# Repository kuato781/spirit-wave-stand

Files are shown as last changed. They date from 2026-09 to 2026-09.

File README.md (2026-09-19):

# Folding Indexed Stand for the Spirit WAVE

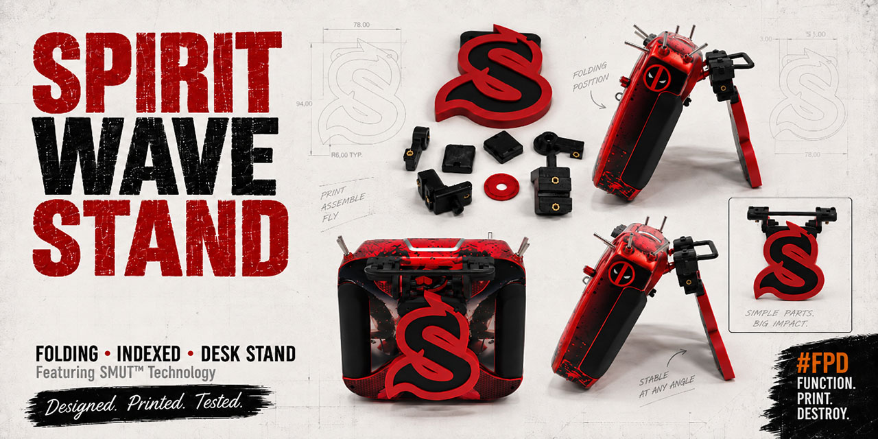
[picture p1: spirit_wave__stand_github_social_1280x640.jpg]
Spirit WAVE Stand


A folding, indexed-position desk stand designed for the round carrying handle on the Spirit WAVE transmitter.

The stand mounts without permanently modifying the radio, folds against the back, preserves normal access to the carrying handle, and uses a spring-loaded ball plunger with a replaceable detent ring to provide positive indexed positions.

This project is a Spirit WAVE implementation of **SMUT™** — **S**ide **M**ount **U**nit **T**echnology — the same retained-pivot architecture proven on the Spektrum iX14, adapted here with WAVE-specific handle cases and a WAVE-specific stand/header.

## What Changed for the WAVE?

The pivot and detent mechanism is intentionally familiar:

- independent left and right retained pivots;
- replaceable keyed detent ring;
- M4 × 0.7 spring-loaded ball plunger;
- square keyed stand blocks that carry shear and twisting load;
- M3/M4 heat-set inserts and conventional metric hardware.

The radio-specific pieces are the **WAVE handle cases/caps** and the **stand/header geometry**.

The WAVE handle cases follow the actual round metal handle path, while the stand uses a reusable 46 mm-center **Header Mule** mechanical core. That makes the architecture:

**standardized mechanical header + radio-specific case interface + whatever stand body you want**

The supplied Spirit-S stand is one implementation of that architecture.

## Start Here

- [Assembly instructions](documentation/assembly-instructions/assembly-instructions.md)
- [Printable three-stage assembly guide](documentation/exploded-view/SpiritWave-assembly-guide.pdf)
- [Hardware buy list](buy-list/Spirit%20WAVE%20Stand%20-%20Buy%20List.md)
- [Bambu Studio notes](bambu-studio-3mf/bambu-studio-profile.md)
- [Individual STL/SCAD files](stl-scad/)
- [Product photos](documentation/product-images/)

For Bambu Studio users, ready-to-slice projects are provided separately for the mounting hardware and stand:

- [SpiritWave_all_mounting_hardware.3mf](bambu-studio-3mf/mounting-hardware/SpiritWave_all_mounting_hardware.3mf)
- [SpiritWave-Stand.3mf](bambu-studio-3mf/stand/SpiritWave-Stand.3mf)

A merged stand STL is also provided for non-Bambu workflows:

- [SpiritWave-Stand-merged.stl](stl-scad/stand/SpiritWave-Stand-merged.stl)

## Product Photos

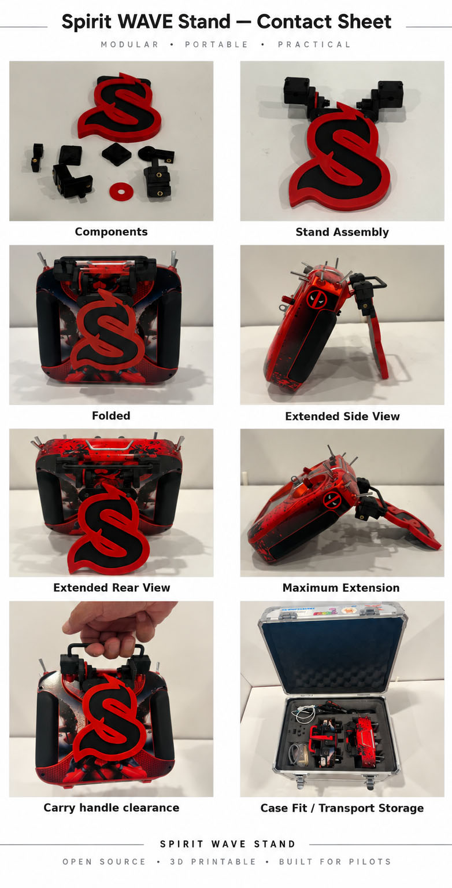
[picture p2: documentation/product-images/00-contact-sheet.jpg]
Spirit WAVE stand contact sheet


The product-image directory contains photographs of the actual printed parts and completed assembly, including separate components, assembled and folded positions, extension views, carrying-handle clearance, and transport-case fit.

These are photographs of the physical build, not CAD renders.

## Important WAVE-Specific Assembly Notes

### Ball-plunger insert collar

Because of the print geometry around the M4 ball-plunger insert, the collar may not seat perfectly cleanly after printing.

If needed, **lightly clean the collar/opening with a reamer** before installing the insert. Remove only enough material to clean up the printed opening; do not enlarge the bore unnecessarily.

### Common case caps

The two case caps are identical. There is no left cap and right cap.

Install each cap with the **beveled edge facing away from the radio**.

Tighten the cap screws until you feel a **good bite** and the cases are secure on the handle. A **visible gap between the cap and case body is normal**; the cap does not need to close flush.

Do not keep tightening simply to eliminate the gap.

### Transport case

> **The radio will not fit in the stock Spirit case with this stand installed unless you are willing to modify the case.**

The physical build shown here is transported in a **Spektrum two-radio case**, which is convenient when carrying multiple transmitters.

## Header Mule — Reusable Mechanical Core

The repository includes the SpiritWave Header Mule STL and SCAD in stl-scad/mounting-hardware/.

This header is the reusable mechanical core for alternate stand designs.

A custom stand can be modeled around or through the Header Mule while preserving:

- the 46 mm mounting-center spacing;
- keyed pivot interfaces;
- screw locations;
- header thickness;
- pivot/rotation clearance.

Stand-specific outlines, chamfers, logos, colors and styling can then be added around that mechanical interface.

## Print and Validation Status

The design was developed through repeated physical fitting and printing rather than CAD-only validation:

**measure → model → print → test → revise**

The WAVE-specific case geometry, common cap, pivot mechanism, Header Mule and Spirit-S stand have all been physically printed and fitted.

PETG is the intended production material for the current build. The supplied Bambu Studio projects are the easiest starting point because they preserve the prepared object layout and stand color separation.

As with any 3D-printed mechanical part, verify fit and motion on your own printer before relying on the stand.

## AI-Assisted Design and Development

This project was developed with AI assistance.

AI was used throughout the iterative process to help translate physical measurements into printable geometry, revise handle-path and case fit, preserve and adapt the SMUT™ pivot architecture, develop the reusable Header Mule, refine the stand outline and multicolor geometry, evaluate clearances and fastener placement, and organize printable artifacts and documentation.

The generated geometry was never treated as correct simply because it looked correct on screen.

The printer and the actual radio got the final vote. :-)

## Repository Organization

| Directory | Contents |
|---|---|
| bambu-studio-3mf/ | Ready-to-slice Bambu Studio projects and print notes |
| buy-list/ | Required metric hardware and inserts |
| documentation/assembly-instructions/ | Detailed Markdown assembly instructions |
| documentation/exploded-view/ | Printable PDF assembly guide and page images |
| documentation/product-images/ | Photographs of the physical build |
| stl-scad/mounting-hardware/ | WAVE case hardware, reusable Header Mule and source/reference geometry |
| stl-scad/stand/ | Spirit WAVE stand STL/SCAD components and merged STL |

Unlike the iX14 project, this repository has **no V1/V2 split**. It contains the current Spirit WAVE implementation directly at the repository root.

## Important Safety Information

- This is a desk/simulator stand, **not a replacement carrying handle**.
- Inspect every print, heat-set insert and fastener before use and periodically afterward.
- Confirm the stand is stable before placing the radio on an elevated, uneven or windy surface.
- Never force the stand beyond its intended range of motion.
- Read [DISCLAIMER.md](DISCLAIMER.md) before printing or using the design.

## Unofficial Community Project

This is an independent community project and is not affiliated with or endorsed by Spirit System.

Spirit, Spirit System, WAVE, associated logos and other brand identifiers remain the property of their respective owners. Their appearance here identifies the compatible transmitter and the physical community build; it does not imply sponsorship or endorsement.

## License

This project is provided under the [Creative Commons Attribution-NonCommercial 4.0 International License](LICENSE).

You may print, copy, share and modify the files for noncommercial purposes with attribution. Changes must be identified.

The original files and derivatives may not be sold or otherwise used commercially without separate permission from the creator.

## Why?

Because apparently the natural progression of:

**RC helicopters + 3D printing + AI + excessive iteration**

is building a modular indexed stand architecture and then adapting it to every transmitter that wanders into the shop.

And that's pretty kewl. :-D

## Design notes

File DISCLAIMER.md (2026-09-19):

# Use at Your Own Risk

The design files, models, print profiles, instructions, photographs and other materials in this repository are provided for personal, noncommercial use on an **as-is** and **as-available** basis.

## No warranty

No warranty or representation is made that the materials are accurate, complete, error-free, safe, suitable for a particular purpose or compatible with any specific printer, material, tool, device or application.

3D-printed parts can vary significantly because of printer calibration, filament condition, material selection, slicer settings, print orientation, layer adhesion, environmental exposure, assembly technique, hardware tolerances and normal wear.

## Your responsibility

You are solely responsible for determining whether a design is suitable for your intended use. Before relying on any printed part or procedure, you should:

- Review the design, dimensions, hardware and instructions.
- Confirm that your printer, material and slicer settings are appropriate.
- Inspect every print for cracks, poor layer adhesion, deformation or other defects.
- Verify the fit, alignment, fasteners, inserts and range of motion during assembly.
- Test the completed item in a controlled and safe environment.
- Reinspect printed parts and hardware periodically and replace anything damaged, loose or worn.
- Independently verify any measurements, alignments, control settings or mechanical adjustments that could affect equipment operation or safety.

Do not assume that a successful print or another user's successful result guarantees that your copy will perform the same way.

## Assumption of risk

By downloading, printing, modifying, assembling or using these materials, you accept all associated risks. These may include failed prints, damaged filament or tools, ruined project materials, damage to equipment or property, loss of use and personal injury.

These materials are not professionally engineered, certified or tested as safety equipment. Do not use them for life-support, fall-protection, structural, load-bearing, emergency or other safety-critical applications.

## Radio and carrying case

This stand changes the external profile of the Spirit WAVE transmitter.

The assembled radio does **not** fit the stock Spirit carrying case without modification. Any carrying-case modification, alternate case selection, packing method or transport decision is entirely the user's responsibility.

The stand is a desk/simulator accessory and is **not a replacement carrying handle**.

## Limitation of liability

To the maximum extent permitted by applicable law, the creator and contributors will not be liable for any direct, indirect, incidental, special, consequential, exemplary or other loss, damage, cost or injury arising from the materials or their use, modification, assembly or inability to be used.

## Modifications and redistribution

If you modify or redistribute these materials, clearly identify your changes. You are responsible for validating your modified version and should preserve this disclaimer or provide an equivalent notice to downstream users.

## Trademarks and affiliation

This is an independent community project and is not affiliated with or endorsed by Spirit System.

Spirit, Spirit System, WAVE, associated logos and other brand identifiers remain the property of their respective owners.

## Relationship to the license

This disclaimer supplements the repository's [LICENSE](LICENSE) file and does not replace or modify its terms. If there is any conflict, the license controls.

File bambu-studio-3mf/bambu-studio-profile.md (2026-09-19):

# Bambu Studio Notes — Spirit WAVE Stand

The repository contains two prepared Bambu Studio projects:

- [mounting-hardware/SpiritWave_all_mounting_hardware.3mf](mounting-hardware/SpiritWave_all_mounting_hardware.3mf)
- [stand/SpiritWave-Stand.3mf](stand/SpiritWave-Stand.3mf)

The mounting hardware and stand are separated so they can be printed, reprinted and color-managed independently.

## Recommended material

The current physical build is printed in **PETG**.

Use a PETG profile appropriate for your printer and filament, and verify the printer, build plate, nozzle and filament mapping before slicing.

The supplied 3MF files are the preferred starting point because they preserve the prepared object arrangement and, for the stand, the separate black/red geometry used for multicolor printing.

## Stand color objects

The stand is organized around two visual groups:

1. **BLACK — structural core + header**
2. **RED — Spirit-S accent + outside edge**

The repository also includes individual STL/SCAD components and a merged STL for users who do not want to use the Bambu Studio project.

## Stand ironing

The physically validated cosmetic setup used **Topmost surface** ironing on the visible stand surfaces:

- Pattern: Rectilinear
- Speed: 25 mm/s
- Flow: 12%
- Line spacing: 0.18 mm
- Inset: 0.21 mm

These settings are intended for the cosmetic top surfaces. Vertical sidewalls are controlled by the model geometry and normal perimeter printing, not by ironing.

## Pre-print checks

Before starting a print:

- confirm all active objects are assigned to the intended PETG spools;
- verify the mounting-hardware and stand projects use the correct printer and plate;
- inspect the sliced preview for unexpected supports, gaps or missing color regions;
- confirm the stand's black/red objects remain aligned;
- inspect first layers before leaving the printer unattended.

## Assembly-sensitive printed features

Two printed areas deserve extra attention after printing:

- **M4 ball-plunger insert collar:** because of the print geometry, the collar/opening may need a very light cleanup with a reamer before the insert seats cleanly.
- **Common case caps:** both caps are identical. Install the beveled edge away from the radio. A visible cap-to-body gap is normal after tightening to a good bite.

Do not remove excess material simply to make cosmetic gaps disappear; fit and secure clamping matter more than a flush seam.

## Transport note

The Spirit WAVE with this stand installed does **not** fit the stock Spirit case unless the case is modified.

The documented physical build is transported in a Spektrum two-radio case.

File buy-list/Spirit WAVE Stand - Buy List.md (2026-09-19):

# Spirit WAVE Stand - Buy List

The Spirit WAVE implementation reuses the proven SMUT™ pivot/detent hardware from the Spektrum iX14 V2 design. The case geometry and stand are radio-specific, but the insert and fastener stack is otherwise the same.

### Heated inserts
- [ ] **6 × M3 heat-set inserts**, approximately **5 mm OD × 5 mm long**
- [ ] **1 × M4 heat-set insert**, approximately **6 mm OD × 6 mm long**

### Ball plunger
- [ ] **1 × M4 × 0.7 spring-loaded ball plunger**
  - Approximately **8-9 mm overall threaded-body length**
  - Approximately **2.5 mm ball**
  - Tested hardware elastic range: **3-15 N**

### Bolts, washers and nuts
- [ ] **2 × M4 × 20 mm socket-head or button-head screws**
- [ ] **2 × M4 Nyloc nuts**
- [ ] **2 × M4 flat washers**
- [ ] **4 × M3 × 12 mm socket-head or button-head screws**
- [ ] **2 × M3 × 8 mm button-head screws**
- [ ] **2 × M3 flat washers**

### Optional
- [ ] Small amount of **removable, non-permanent threadlocker** (for example, blue Loctite) for the ball-plunger threads

> **Note:** The Spirit WAVE cases use the same insert and fastener arrangement as the proven iX14 V2 SMUT™ mechanism. The WAVE-specific changes are the handle-fitting case geometry and the stand/header geometry.

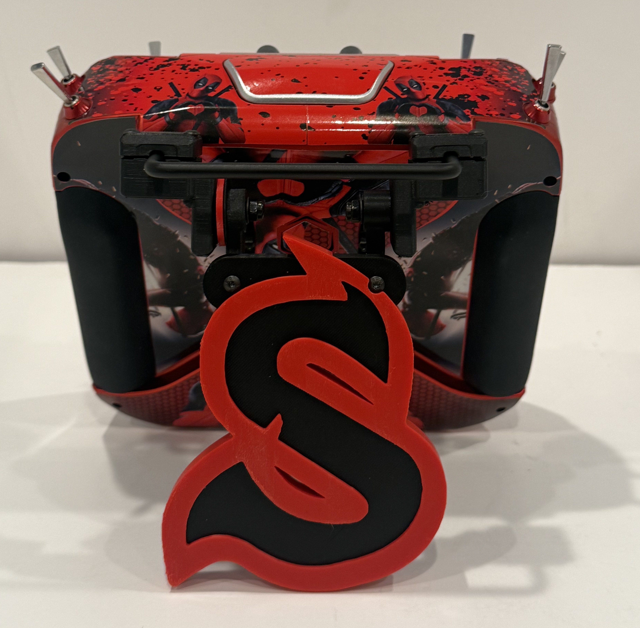
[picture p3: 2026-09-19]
documentation/product-images/05-extended.jpg

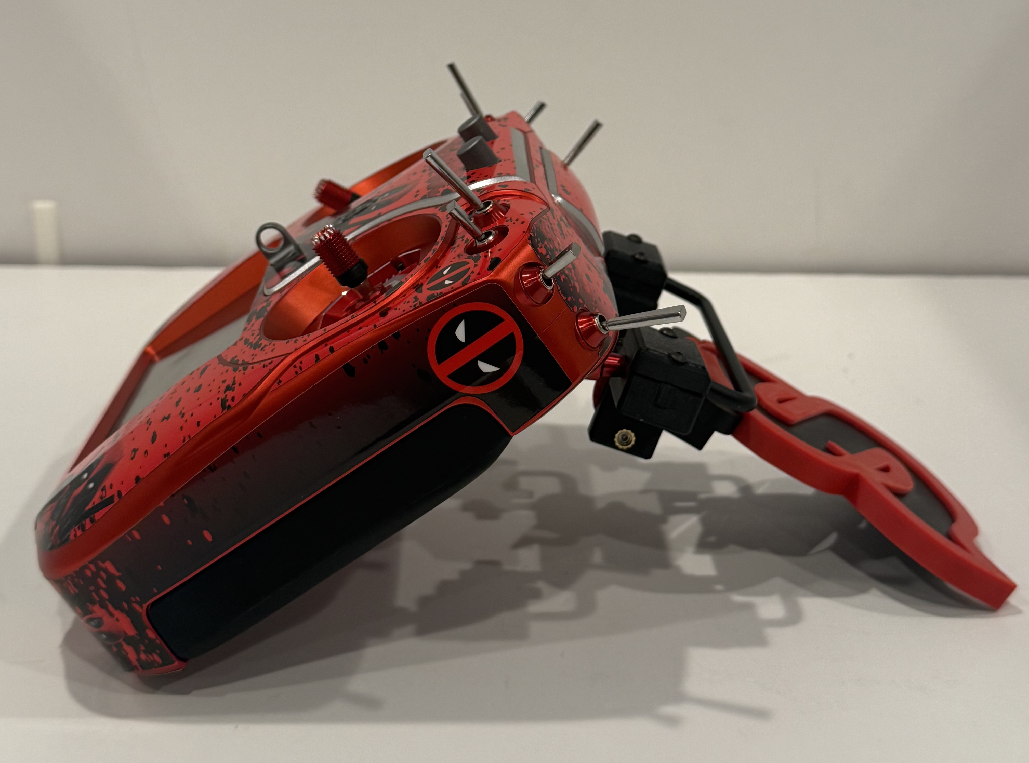
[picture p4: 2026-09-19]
documentation/product-images/07-extended_side_max.jpg

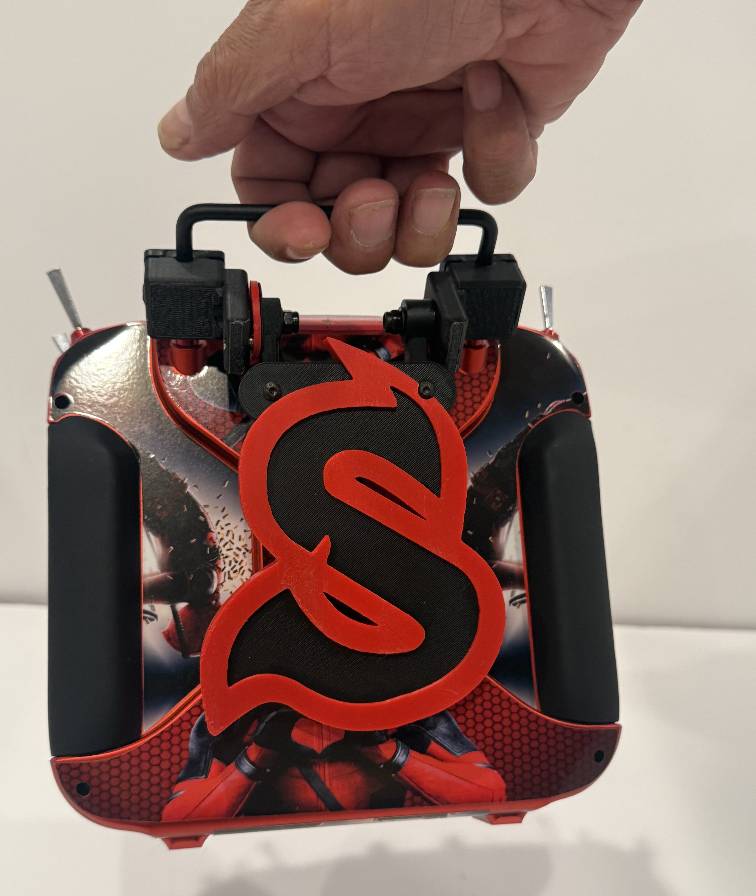
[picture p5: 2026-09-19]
documentation/product-images/08-clearance.jpg

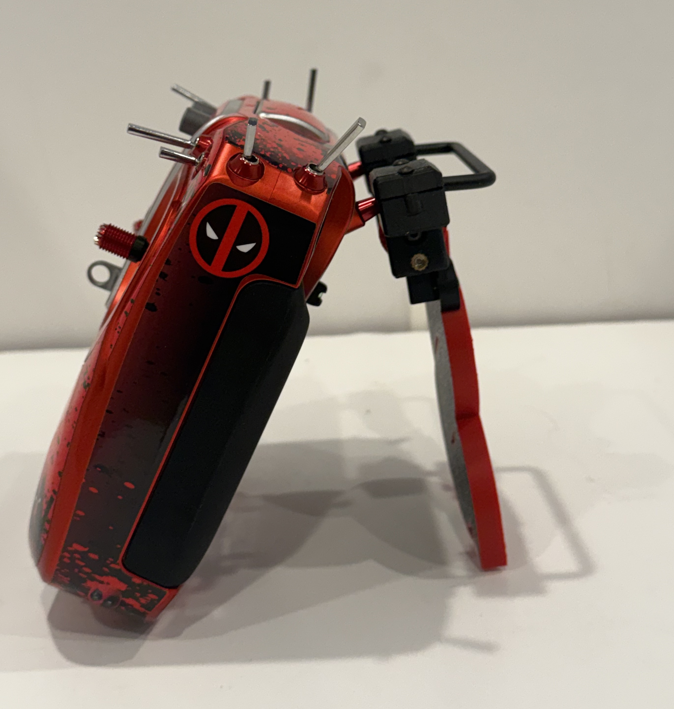
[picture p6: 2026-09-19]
documentation/product-images/04-extended_side.jpg

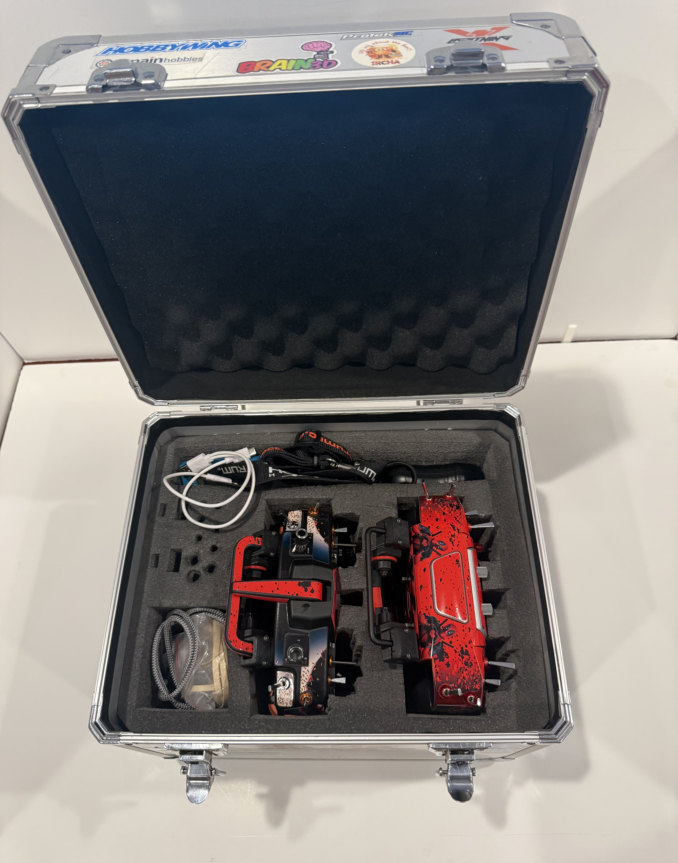
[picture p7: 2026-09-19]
documentation/product-images/10-carrier-fit.jpg

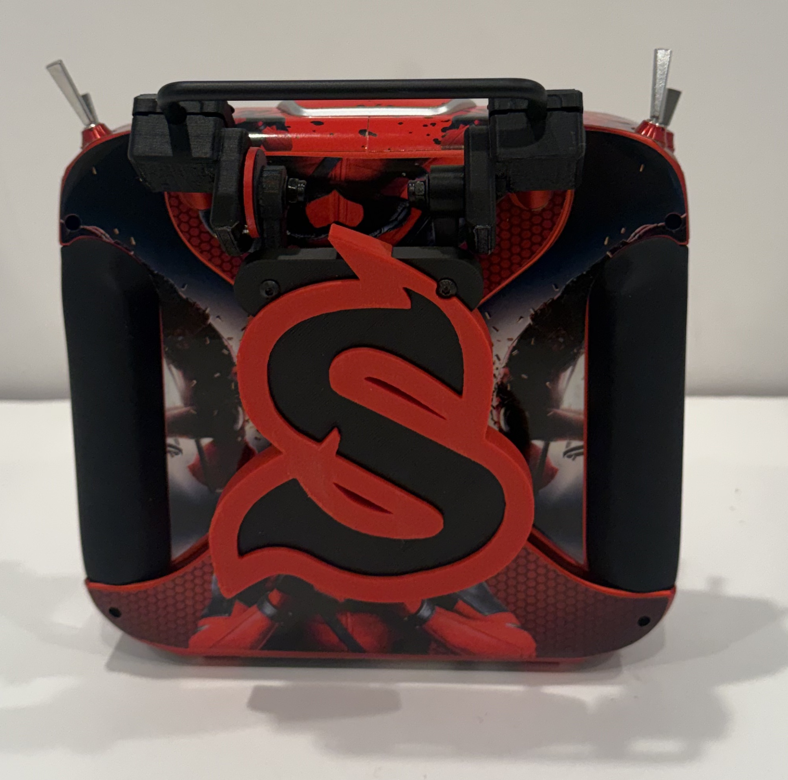
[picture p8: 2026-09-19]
documentation/product-images/03-folded.jpg

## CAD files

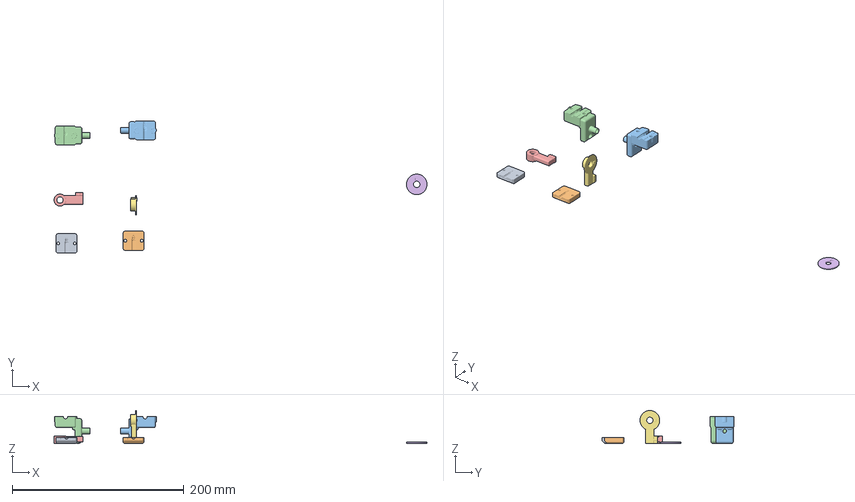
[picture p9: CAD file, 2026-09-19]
bambu-studio-3mf/mounting-hardware/SpiritWave_all_mounting_hardware.3mf
435.0 x 154.2 x 38.5 mm
SpiritWave-common-case-cap.stl x 2
SpiritWave-left-plain-case-body.stl
SpiritWave-right-detent-case-body.stl
SpiritWave-left-plain-pivot-stub.stl
SpiritWave-replaceable-detent-ring.stl
SpiritWave-right-detent-pivot-stub.stl

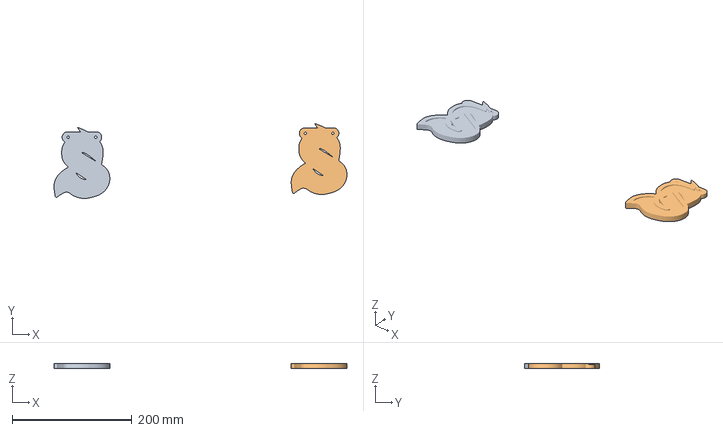
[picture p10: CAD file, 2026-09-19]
bambu-studio-3mf/stand/SpiritWave-Stand.3mf
488.6 x 124.7 x 9.00 mm
Assembly
SpiritWave-Stand-merged.stl

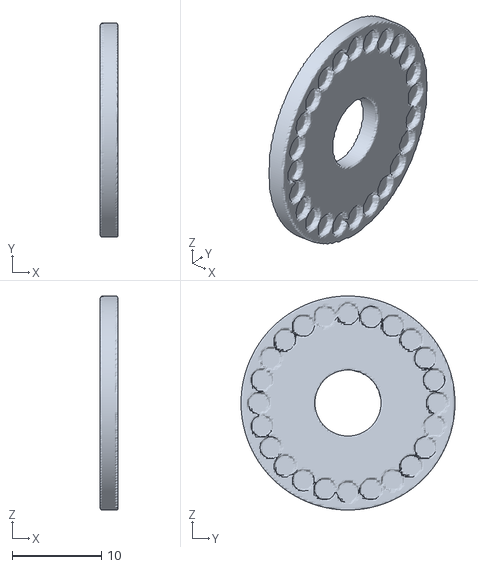
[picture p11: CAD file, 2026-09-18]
stl-scad/mounting-hardware/SpiritWave-replaceable-detent-ring.stl
2.00 x 24.0 x 24.0

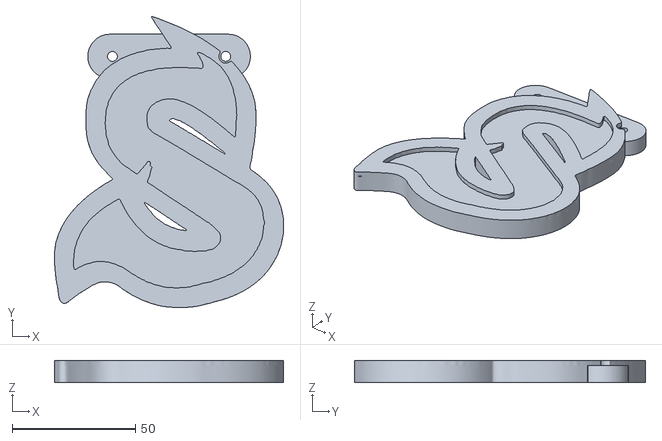
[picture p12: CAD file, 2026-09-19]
stl-scad/stand/SpiritWave-Stand-merged.stl
93.1 x 118.1 x 9.00

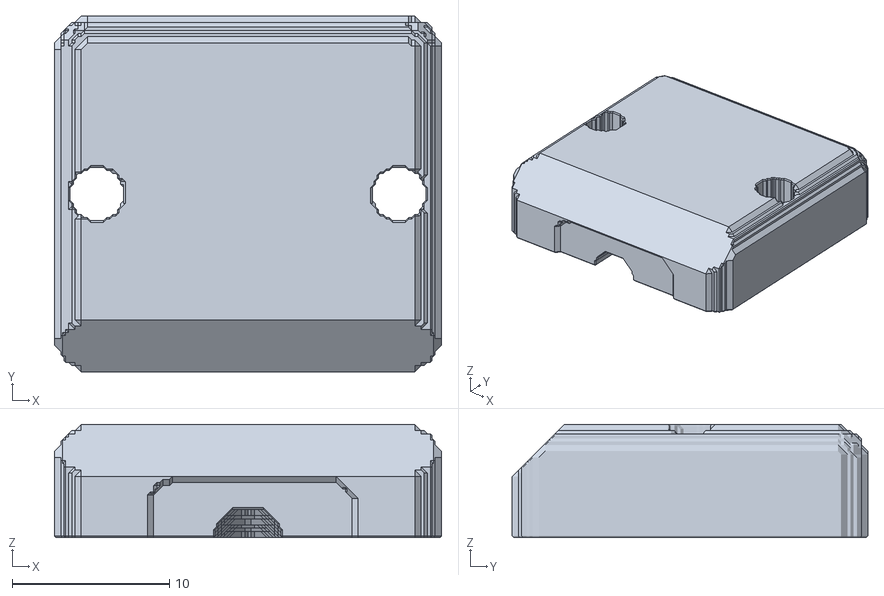
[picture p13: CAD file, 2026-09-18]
stl-scad/mounting-hardware/SpiritWave-common-case-cap.stl
24.6 x 22.6 x 7.20

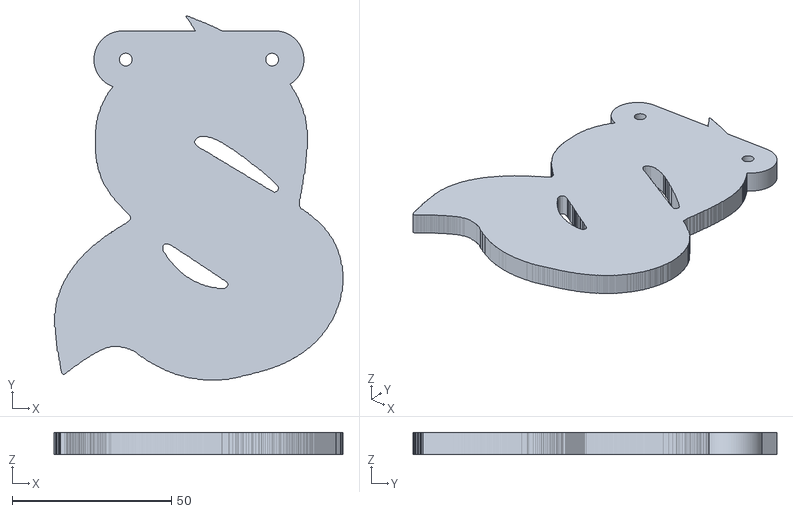
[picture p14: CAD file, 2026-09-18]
stl-scad/stand/SpiritWave-BLACK.stl
90.8 x 114.4 x 7.00

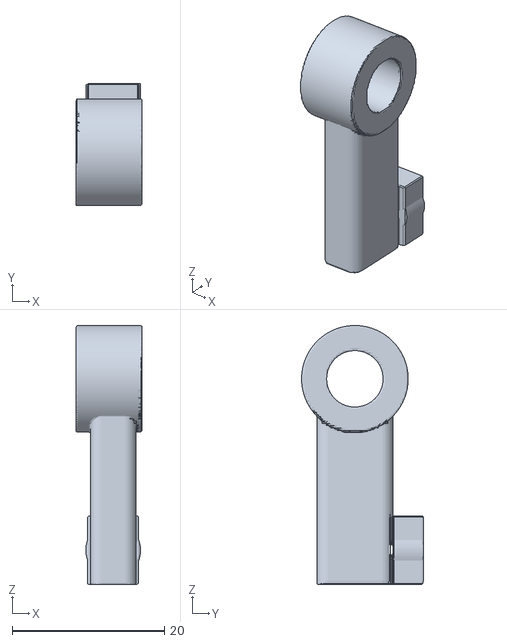
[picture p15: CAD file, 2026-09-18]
stl-scad/mounting-hardware/SpiritWave-left-plain-pivot-stub.stl
8.70 x 16.0 x 34.0

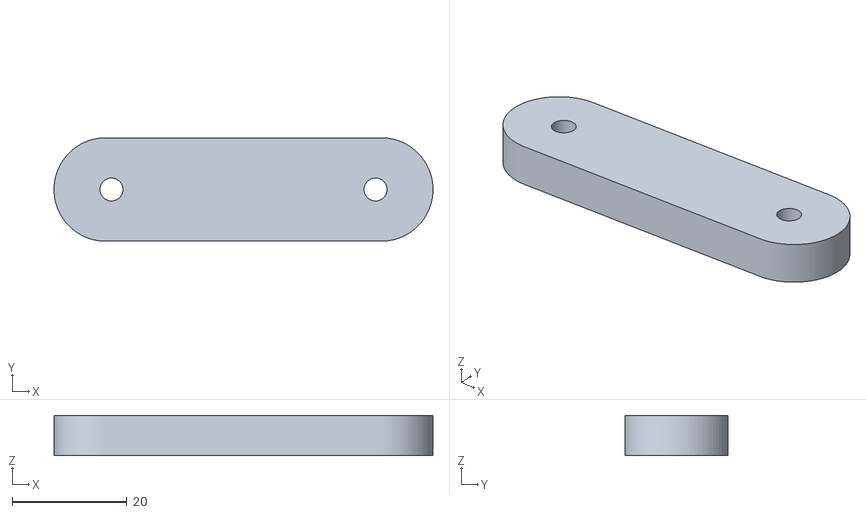
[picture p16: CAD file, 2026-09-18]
stl-scad/stand/SpiritWave-BLACK-HEADER.stl
66.0 x 18.0 x 7.00

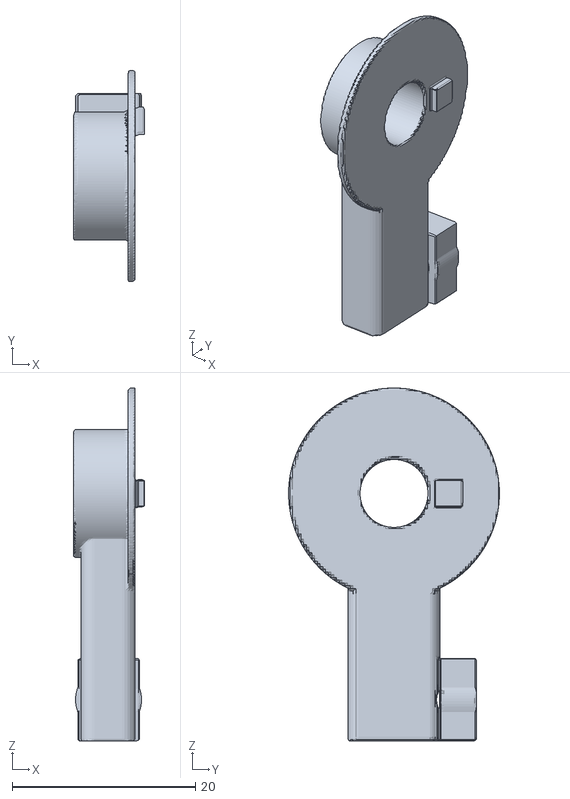
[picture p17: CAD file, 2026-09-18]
stl-scad/mounting-hardware/SpiritWave-right-detent-pivot-stub.stl
7.70 x 23.0 x 38.5

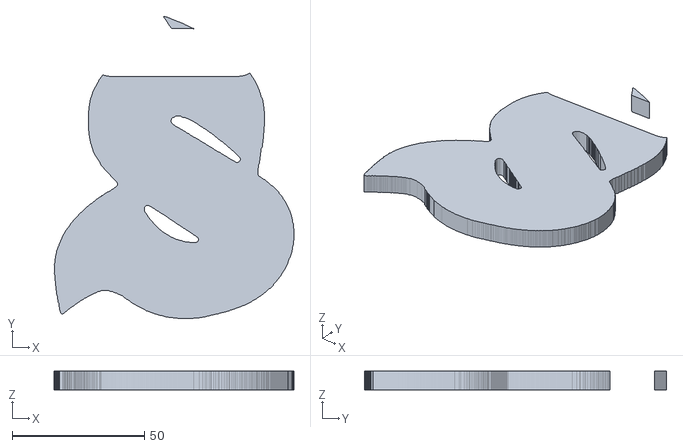
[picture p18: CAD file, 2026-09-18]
stl-scad/stand/SpiritWave-BLACK-BODY.stl
90.8 x 114.4 x 7.00

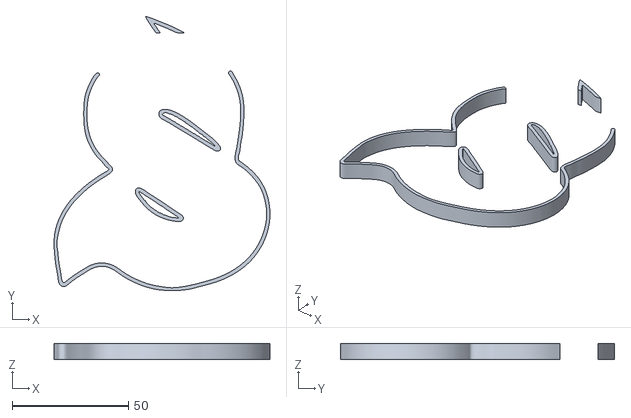
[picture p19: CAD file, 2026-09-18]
stl-scad/stand/SpiritWave-RED-LOWER.stl
93.1 x 118.1 x 7.00

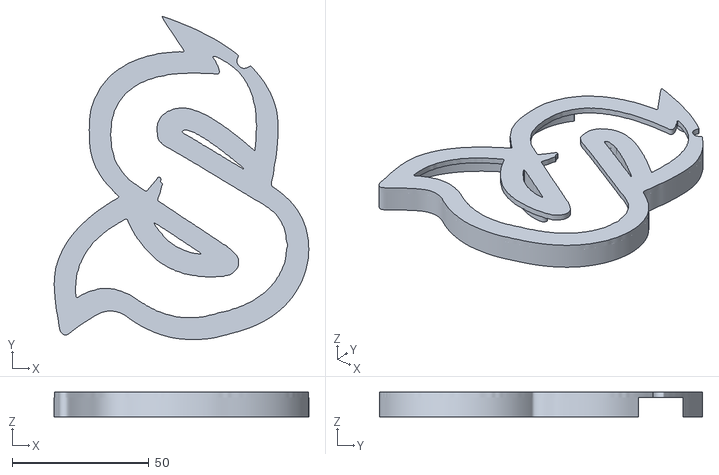
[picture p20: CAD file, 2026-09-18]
stl-scad/stand/SpiritWave--RED.stl
93.1 x 118.1 x 9.00

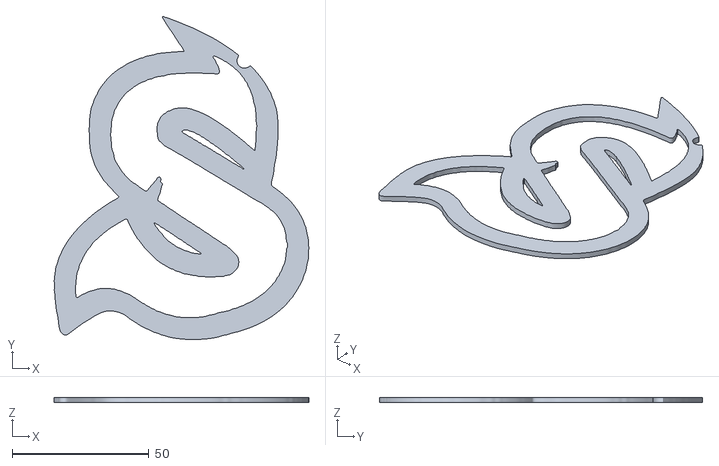
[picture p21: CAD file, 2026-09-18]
stl-scad/stand/SpiritWave--RED-RAISED.stl
93.0 x 118.1 x 2.00

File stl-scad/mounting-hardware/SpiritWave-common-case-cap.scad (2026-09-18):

// Spirit WAVE SMUT™ — Mule 0.16 common case-cap source reference
//
// The 0.16 common cap is carried forward unchanged from the proven 0.11 cap.
// The printable STL in the package is the authoritative frozen geometry.

fit_d = 4.90;              // Spirit WAVE round-handle channel
m3_clearance_d = 3.40;     // free-pass M3 cap screw hole
cap_bottom_trim = 1.00;    // 0.11: shortened 1 mm from bottom

// Round handle architecture:
// cap receives the TOP 180° of the 4.90 mm channel;
// case body receives the BOTTOM 180° cradle.
// Left/right use the same common cap because the WAVE rails are parallel.

// Insert/collar geometry belongs to the case body, not this cap.

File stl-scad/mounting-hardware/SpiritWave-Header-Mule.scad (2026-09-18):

DONOR="/mnt/data/ix14_v2_stand.stl";
SHIFT=1.5; YMIN=-9; YMAX=9; ZMIN=0; ZMAX=7;
R=9; C=24; PIVOT_X=23; THRU_R=2; BOTTOM_FILL_H=1.05;

module donor_header(){
  intersection(){
    import(DONOR,convexity=30);
    translate([-100,YMIN,ZMIN]) cube([200,YMAX-YMIN,ZMAX-ZMIN]);
  }
}
module left_half(){
  intersection(){
    donor_header();
    translate([-100,-100,-10]) cube([100,200,30]);
  }
}
module right_half(){
  intersection(){
    donor_header();
    translate([0,-100,-10]) cube([100,200,30]);
  }
}
module widened_header(){
  union(){
    translate([-SHIFT,0,0]) left_half();
    translate([SHIFT,0,0]) right_half();
    translate([-SHIFT,YMIN,ZMIN]) cube([2*SHIFT,YMAX-YMIN,ZMAX-ZMIN]);
  }
}
module capsule_2d(){
  hull(){
    translate([-C,0]) circle(r=R,$fn=180);
    translate([ C,0]) circle(r=R,$fn=180);
  }
}
module capsule_header(){
  intersection(){
    widened_header();
    linear_extrude(height=ZMAX,convexity=30) capsule_2d();
  }
}
module bottom_flat_fill(){
  difference(){
    linear_extrude(height=BOTTOM_FILL_H,convexity=30) capsule_2d();
    for(x=[-PIVOT_X,PIVOT_X])
      translate([x,0,-0.1]) cylinder(h=BOTTOM_FILL_H+0.2,r=THRU_R,$fn=96);
  }
}
union(){
  capsule_header();
  bottom_flat_fill();
}

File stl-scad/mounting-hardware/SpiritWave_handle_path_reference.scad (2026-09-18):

// Spirit WAVE SMUT™ — proven Mule 0.5 handle-path reference
fit_d = 4.90;
straight = 10.0;
bend_r = 6.0;
bend_deg = 15.047020063425533;
tail_len = 10.102419240115;
seam_z = 2.70;
// Strict centerline: straight -> ONE circular bend -> tangent straight.

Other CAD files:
stl-scad/mounting-hardware/SpiritWave-Header-Mule.stl
stl-scad/stand/SpiritWave--RED.scad
stl-scad/stand/SpiritWave-RED-LOWER.scad
stl-scad/stand/SpiritWave-RED-RAISED.scad

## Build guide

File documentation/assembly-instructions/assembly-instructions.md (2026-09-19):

# Assembly Instructions - Spirit WAVE Stand SMUT™ System

[Download the printable three-stage assembly guide (PDF)](../exploded-view/SpiritWave-assembly-guide.pdf)

These instructions apply to the Spirit WAVE implementation of **SMUT™** - **S**ide **M**ount **U**nit **T**echnology. The mechanism uses independent left and right pivot assemblies clamped around the WAVE's round metal handle, then joins them with the Spirit WAVE stand/header assembly.

**Left and right are always described while looking at the front of the radio.**

> **Hardware status:** the pivot, detent and mounting hardware are carried forward from the physically validated iX14 SMUT™ mechanism. The Spirit WAVE uses radio-specific case geometry and a WAVE-specific stand/header while retaining the same pivot-stub, replaceable detent-ring and ball-plunger architecture.

## Recommended print files

For Bambu Studio users:

- [Spirit WAVE mounting hardware 3MF](../../bambu-studio-3mf/mounting-hardware/SpiritWave_all_mounting_hardware.3mf)
- [Spirit WAVE stand 3MF](../../bambu-studio-3mf/stand/SpiritWave-Stand.3mf)

Individual STL/SCAD files are also available under stl-scad/. A merged stand STL is available at [SpiritWave-Stand-merged.stl](../../stl-scad/stand/SpiritWave-Stand-merged.stl).

## Printed parts

| Quantity | Part |
| ---: | --- |
| 1 | Left plain case body |
| 2 | Common case cap |
| 1 | Left plain pivot stub |
| 1 | Right detent case body |
| 1 | Right detent pivot stub |
| 1 | Replaceable detent ring |
| 1 | Spirit WAVE stand assembly |

The reusable **SpiritWave Header Mule** is provided as a design core/reference for alternate stand bodies. It is already incorporated into the supplied stand and is **not an additional printed part** when using the current stand 3MF.

Use the [Spirit WAVE buy list](<../../buy-list/Spirit WAVE Stand - Buy List.md>) for the complete hardware list.

## Insert locations

Install all heat-set inserts before mounting the cases to the radio.

- **4 × M3 inserts:** two reinforced cap-screw pockets in each case body
- **2 × M3 inserts:** one square stand-mounting block on each pivot stub
- **1 × M4 insert:** spring-plunger bore in the right detent case body

Use the alignment feature supplied with your heat-set tool, such as an insert-centering nub, whenever one is available. If your heat-set setup does not already provide an alignment solution, an appropriate screw may be threaded loosely into the insert to help keep it straight. Press the insert into its reinforced collar and allow the part to cool completely before applying load.

> **Ball-plunger insert collar:** because of the nature of the print and the location of the M4 plunger insert, the printed collar/opening may not seat perfectly cleanly. If needed, **lightly clean it with a reamer** before installing the insert. Remove only enough material to clean the opening; do not unnecessarily enlarge the bore.

[Stage 1: build the left and right pivot assemblies](../exploded-view/images/step1.png)

## 1. Assemble the right detent pivot

1. Place the replaceable detent ring on the support face of the right detent pivot stub.
2. Align the asymmetric square key and recess. The ring should seat fully without force.
3. Orient the detent pockets toward the right case body and its ball-plunger bore.
4. Slide the right pivot stub over the case body's 7 mm pivot sleeve.
5. Install the M4 pivot screw through the case body, sleeve and stub.
6. Fit the M4 washer on the Nyloc side, then install the M4 Nyloc nut.
7. Tighten until the hardware is firmly seated. Confirm that the sleeve shoulder prevents the stub from being pinched and that the stub still rotates freely.

## 2. Assemble the left plain pivot

1. Slide the left plain pivot stub over the left case body's pivot sleeve.
2. Install the M4 pivot screw through the case body, sleeve and stub.
3. Fit the M4 washer on the Nyloc side, then install the M4 Nyloc nut.
4. Tighten until firmly seated and confirm smooth, free rotation.

## 3. Mount the case assemblies to the WAVE handle

[Stage 2: attach the case assemblies to the WAVE handle](../exploded-view/images/step2.png)

1. Place the completed left and right case assemblies around their corresponding sides of the Spirit WAVE round metal handle.
2. Fit one **common case cap** to each case body. The two caps are identical; there is no left/right cap assignment.
3. Orient each common cap with its **beveled edge facing away from the radio**.
4. Make sure the handle is fully seated in the curved channel in each case and cap.
5. Install two M3 × 12 screws through each cap.
6. Snug the four cap screws only enough to hold the assemblies in position while the stand/header is fitted and used to square both sides.

Washers are not required under the case-cap screws.

> **Normal cap fit:** after final tightening there will be a **visible gap** between each cap and case body. This is expected. Tighten until you feel a **good bite** and the assembly is secure on the handle; do not overtighten simply to force the cap flush.

## 4. Attach the Spirit WAVE stand

[Stage 3: attach, square and tighten the Spirit WAVE stand](../exploded-view/images/step3.png)

1. Align the stand/header's two keyed recesses with the square mounting blocks on the pivot stubs.
2. Seat both mounting blocks completely in the header recesses.
3. Install one M3 × 8 button-head screw and M3 washer through each header hole and into the insert in the corresponding pivot-stub block.
4. Leave both stand screws slightly loose during alignment.

The keyed mounting blocks carry the stand's shear and twisting loads; the M3 screws retain and clamp the connection.

## 5. Square and tighten the assembly

1. Push both handle-mounted case assemblies as far toward the radio body as they will naturally seat.
2. Use the attached stand/header to bring both pivot assemblies square and parallel.
3. Tighten the four M3 × 12 cap screws evenly, alternating between screws so each cap clamps uniformly around the handle.
4. Stop when the caps have a secure **good bite** on the handle. A visible cap-to-body gap is normal.
5. Tighten the two M3 × 8 stand screws and washers.
6. Fold and deploy the stand through its complete travel to confirm that neither side binds or shifts.

Do not overtighten the cap screws against the radio handle.

## 6. Install and adjust the ball plunger

1. Use something thin, such as an awl or straightened paper clip, to place a **small amount of removable, non-permanent threadlocker** inside the receiving threads of the M4 insert. Keep the threadlocker off the surrounding plastic and out of the plunger mechanism.
2. Insert the M4 × 0.7 spring-loaded ball plunger **ball end first** through the access bore, then thread it into the M4 insert in the right detent case body.
3. Advance the plunger a little at a time while repeatedly moving the stand between its fully folded and fully extended positions.
4. Continue making small adjustments until the ball engages the detent recesses solidly at each indexed position without making the pivot overly tight or difficult to move.
5. Cycle the stand repeatedly through its full range. Confirm positive engagement at every position and verify that the replaceable detent ring remains fully seated.

The correct setting is the point at which the detents feel deliberate and secure while the stand still moves smoothly. Do not use permanent threadlocker.

## Final inspection

- Both case assemblies are fully seated on the intended WAVE handle locations
- Both common caps have their beveled edges facing away from the radio
- Both common caps have a secure bite; a visible cap-to-body gap is acceptable and expected
- All four cap screws are evenly tightened
- Both pivot screws are secure with washers and Nyloc nuts
- Both pivots rotate freely without axial looseness
- Detent-ring key is fully seated and pockets face the plunger
- Ball plunger engages each detent recess positively without binding
- Both stand/header keyed recesses are fully seated on the pivot-stub mounting blocks
- Both stand screws have washers and are secure
- Stand deploys smoothly and supports the radio at the intended angle
- Stand folds without contacting the radio body, switches or controls
- Handle opening remains clear for normal carrying

## Transport / case fit

**The radio will not fit in the stock Spirit case with this stand installed unless you are willing to modify the case.**

The documented physical build is transported in a **Spektrum two-radio case**, which also works well when carrying multiple transmitters.

## Safety and maintenance

- This is a desk/simulator stand, not a replacement carrying handle.
- Inspect the printed parts, inserts and fasteners periodically for cracks, loosening or wear.
- Replace the detent ring if its pockets become rounded or inconsistent.
- Recheck cap and stand screws after the first several use cycles.
- Recheck the ball-plunger adjustment after the first several use cycles and whenever engagement begins to feel weak or excessively tight.
- Never force the stand beyond its designed range of motion.
- Use the stand at your own risk and verify stability before placing the radio on any elevated, uneven or windy surface.

## Project status / branding note

This is an unofficial community project and is not affiliated with or endorsed by Spirit System.

The SMUT™ mechanism and reusable WAVE header architecture are independent of the Spirit-S cosmetic stand treatment. A logo-free stand body can use the same case/pivot/detent mechanism and Header Mule interface.

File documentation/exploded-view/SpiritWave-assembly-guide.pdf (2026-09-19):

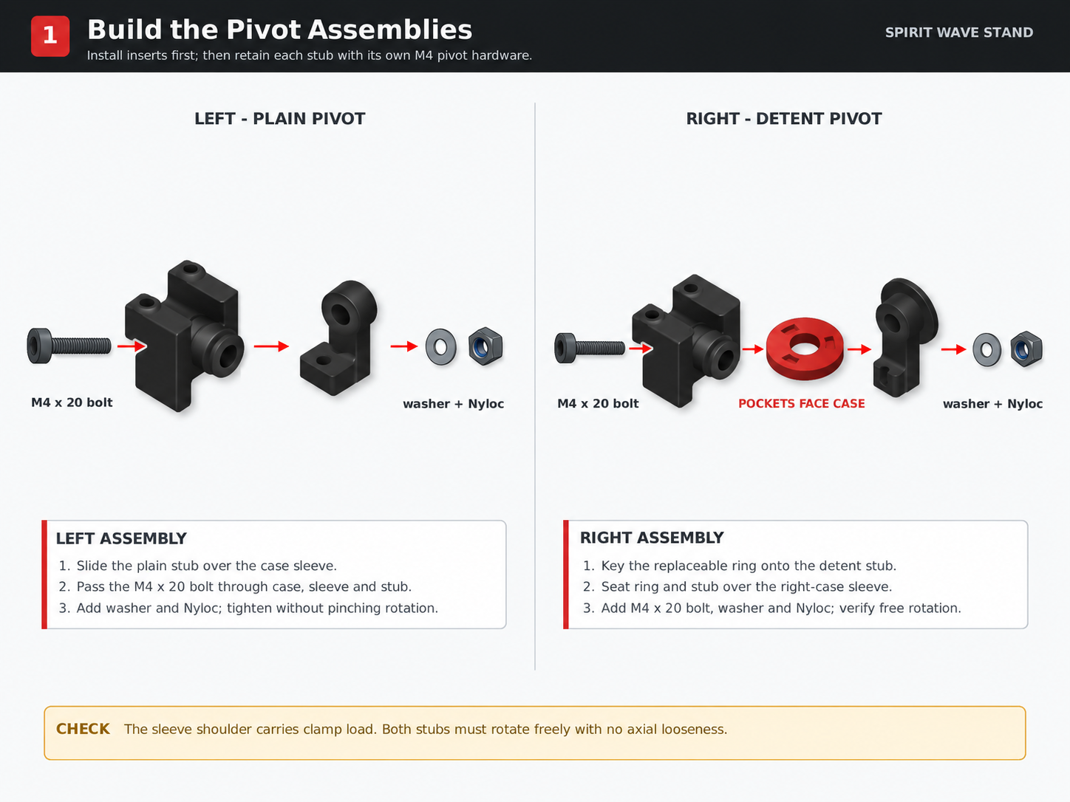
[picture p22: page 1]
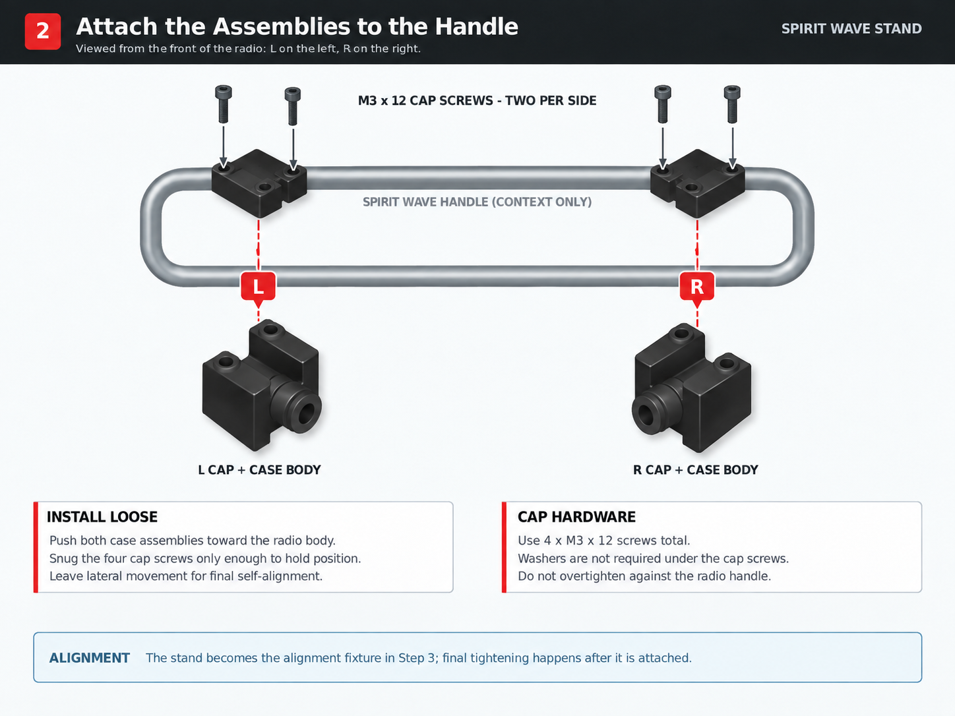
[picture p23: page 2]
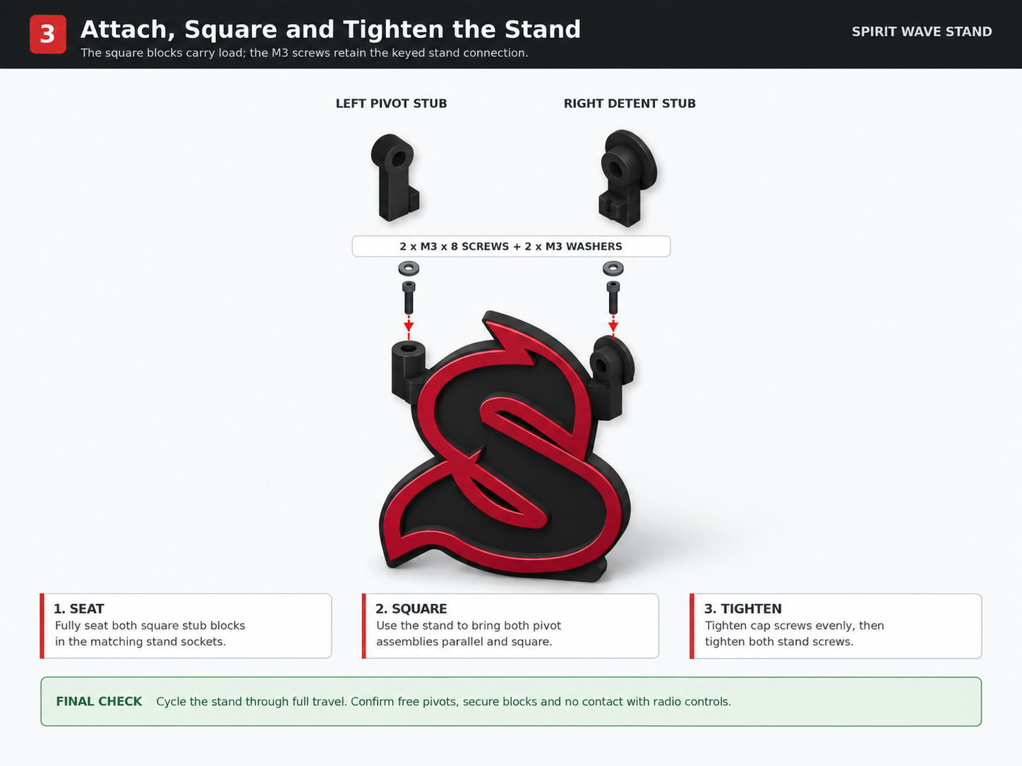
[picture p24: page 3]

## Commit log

2026-09-19 Upload various images and documention artifacts
    [SpiritWave-SpiritS-Stand-Mule-0.11-Bambu.3mf, SpiritWave-Stand-merged.stl, SpiritWave-Stand.3mf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]
2026-09-19 Add Bambu Studio print notes
2026-09-19 Update WAVE assembly notes and links
